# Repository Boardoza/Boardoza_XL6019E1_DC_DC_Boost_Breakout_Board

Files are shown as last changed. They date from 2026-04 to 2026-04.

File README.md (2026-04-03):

# Boardoza XL6019E1  DC-DC Boost Converter Breakout Board

The **Boardoza XL6019E1** is a high-efficiency **DC-DC boost converter breakout board** built around the **XL6019E1** switching regulator IC. It is designed to step up low DC input voltages to higher, regulated output voltage levels while maintaining high efficiency and stable operation.

This board is well suited for **industrial electronics, robotics, LED drivers, automotive systems, battery-powered projects, and embedded applications** where higher voltage outputs such as 12V, 24V, 36V, or 48V are required from lower-voltage sources. Its compact size and simple pinout make it ideal for both prototyping and final product integration.

## [Click here to purchase!](https://www.ozdisan.com/ureticiler/boardoza)

| Front Side | Back Side |
|:---:|:---:|
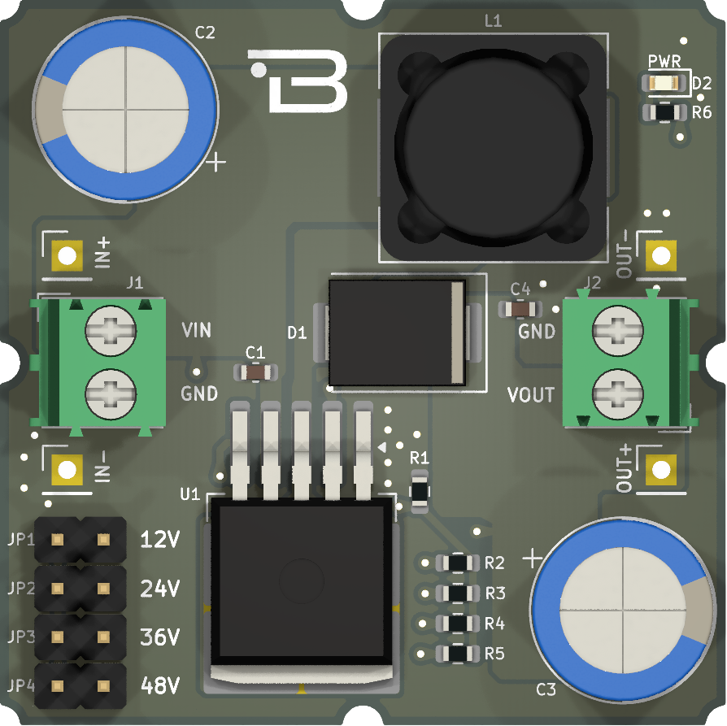
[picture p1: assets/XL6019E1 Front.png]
XL6019 Front
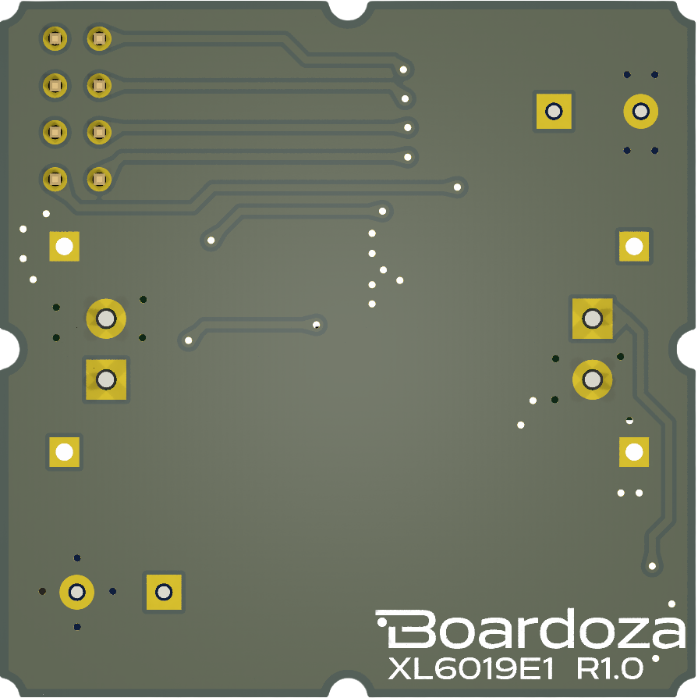
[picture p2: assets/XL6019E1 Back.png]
XL6019 Back
|  |  |

---

## Key Features

- **Wide Input Voltage Range:** Supports input voltages from **5V to 40V**, allowing operation from a wide variety of DC power sources.
- **Selectable Output Voltage Levels:** Provides regulated, selectable output voltages of **12V, 24V, 36V, or 48V** to suit different system requirements.
- **High-Efficiency Boost Conversion:** Designed for high performance with efficiency levels of up to **94%**, minimizing power loss.
- **Fixed Switching Frequency:** Operates at a stable **180 kHz switching frequency** for predictable and reliable behavior.
- **High Switching Current Capability:** Supports up to **5A internal switching current**, suitable for demanding boost applications.

---

## Technical Specifications

**Model:** XL6019E1  
**Manufacturer:** Boardoza  
**Manufacturer IC:** XLSEMI   
**Input Voltage:** 5V – 40V  
**Output Voltage:** 12V, 24V, 36V, 48V (Selectable)  
**Converter Type:** DC-DC Boost Converter  
**Maximum Output Current:** Up to 2A (depending on input voltage and operating conditions)  
**Switching Frequency:** 180 kHz  
**Maximum Switching Current:** 5A  
**Operating Temperature:** -40°C to +125°C  
**Board Dimensions:** 40 mm × 40 mm  

---

## Board Pinout

### **( J1 ) Input Connector**

| Pin Number | Pin Name | Description |
|:---:|:---:|---|
| 1 | VIN | Power Input (5V – 40V) |
| 2 | GND | Ground |

### **( J2 ) Output Connector**

| Pin Number | Pin Name | Description |
|:---:|:---:|---|
| 1 | VOUT | Boosted Output Voltage (12V / 24V / 36V / 48V) |
| 2 | GND | Ground |

---

## Board Dimensions

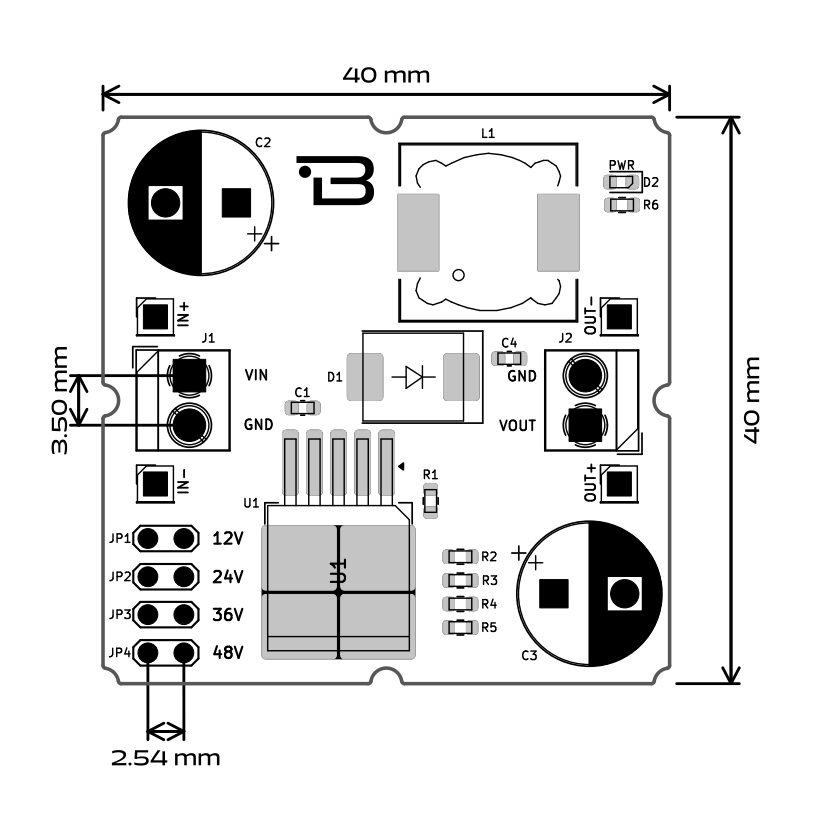
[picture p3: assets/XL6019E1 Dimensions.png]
Board Dimensions


---

## Step Files

[Boardoza XL6019E1.step](./assets/XL6019E1%20Step.step)

---

## Datasheet

[XL6019E1 Datasheet.pdf](./assets/XL6019E1%20Datasheet.pdf)

---

## Version History

- V1.0.0 – Initial Release

---

## Support

- If you have any questions or need support, please contact **support@boardoza.com**

---

## **License**
### **Hardware Design**

[][cc-by-sa]

All hardware design files are licensed under [Creative Commons Attribution-ShareAlike 4.0 International License][cc-by-sa].

[cc-by-sa]: http://creativecommons.org/licenses/by-sa/4.0/
[cc-by-sa-shield]: https://img.shields.io/badge/License-CC%20BY--SA%204.0-lightgrey.svg

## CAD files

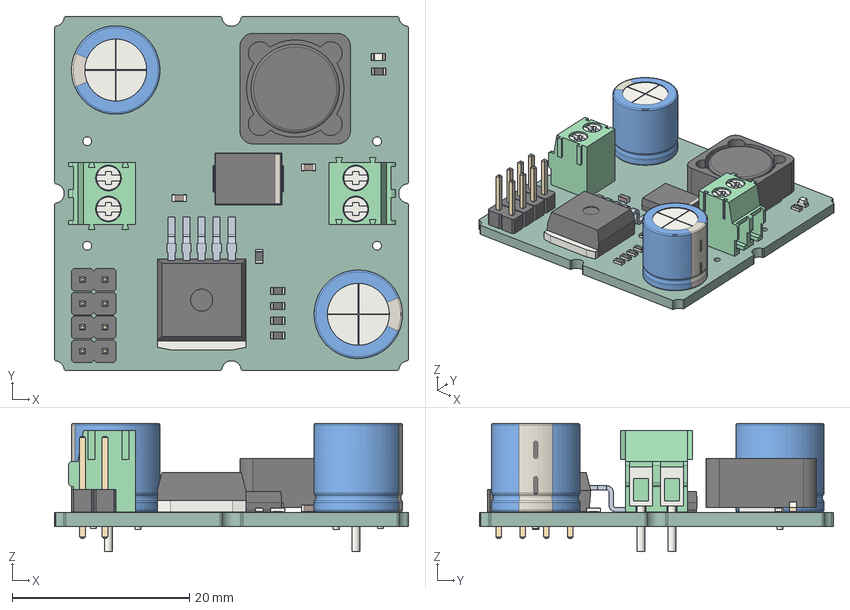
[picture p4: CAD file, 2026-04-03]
assets/XL6019E1 Step.step
40.0 x 40.0 x 14.5 mm
C_0603_1608Metric x 2
TerminalBlock_Phoenix_PT_15_2_35_H_1x02_P350mm_Horizontal x 2
SRR1260
CP_Radial_D100mm_P500mm x 2
PinHeader_1x02_P254mm_Vertical x 4
CQ assembly
R_0603_1608Metric x 6
D_SMC
LED_0603_1608Metric
_autosave-B-XL6019E1-BRK_PCB

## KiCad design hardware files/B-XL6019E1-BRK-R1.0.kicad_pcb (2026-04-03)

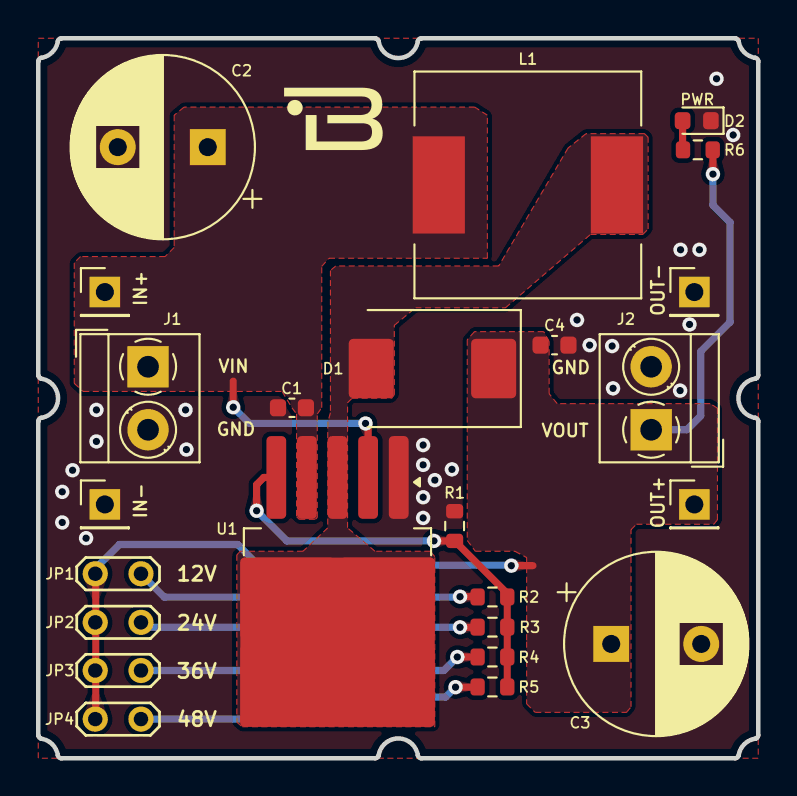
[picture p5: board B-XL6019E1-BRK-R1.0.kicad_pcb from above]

Board: 2 copper layers, 40.0 x 40.0 mm, 24 parts (0 on the bottom side), 10 nets.

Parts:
C1, C4: 1uF; C_0603_1608Metric
C2, C3: 220uF; CP_Radial_D10.0mm_P5.00mm
D1: B560C-13-F; D_SMC
D2: LED; LED_0603_1608Metric
J1, J2: Screw_Terminal_01x02; TerminalBlock_MetzConnect_Type059_RT06302HBWC_1x02_P3.50mm_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
J3, J4, J5, J6: Conn_01x01_Pin; PinHeader_1x01_P2.54mm_Vertical
JP1, JP2, JP3, JP4: Jumper_2_Open; TestPoint_2Pads_Pitch2.54mm_Drill0.8mm
L1: 47uH/5A; L_12x12mm_H4.5mm
R1: 2K; R_0603_1608Metric
R2: 17.4K; R_0603_1608Metric
R3: 36.5K; R_0603_1608Metric
R4: 56K; R_0603_1608Metric
R5: 75K; R_0603_1608Metric
R6: 6.2K; R_0603_1608Metric
U1: XL6019E1; TO-263-5_TabPin3

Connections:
/FB: R1.1, R2.1, R3.1, R4.1, R5.1, U1.5 (FB)
/FBVOUT: C3.1, C4.1, D1.1 (K), J2.1, J6.1, JP1.2 (B), JP2.2 (B), JP3.2 (B), JP4.2 (B), R6.1
/VIN: C1.1, C2.1, J1.1, J4.1, L1.1, U1.2 (EN), U1.4 (VIN)
GND: C1.2, C2.2, C3.2, C4.2, D2.1 (K), J1.2, J2.2, J3.1, J5.1, R1.2, U1.1 (GND)
unnamed: D1.2 (A), L1.2, U1.3 (SW)
unnamed: D2.2 (A), R6.2
unnamed: JP1.1 (A), R2.2
unnamed: JP2.1 (A), R3.2
unnamed: JP3.1 (A), R4.2
unnamed: JP4.1 (A), R5.2

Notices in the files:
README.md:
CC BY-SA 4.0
